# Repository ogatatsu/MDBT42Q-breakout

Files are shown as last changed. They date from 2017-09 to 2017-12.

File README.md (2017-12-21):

# MDBT42Q-breakout

Raytac社製nRF52832モジュールMDBT42Qのブレークアウト基板です。

RedBearLabのBLE Nanoの書き込み機(Daplink)を直接挿して書き込みできるようにしました。

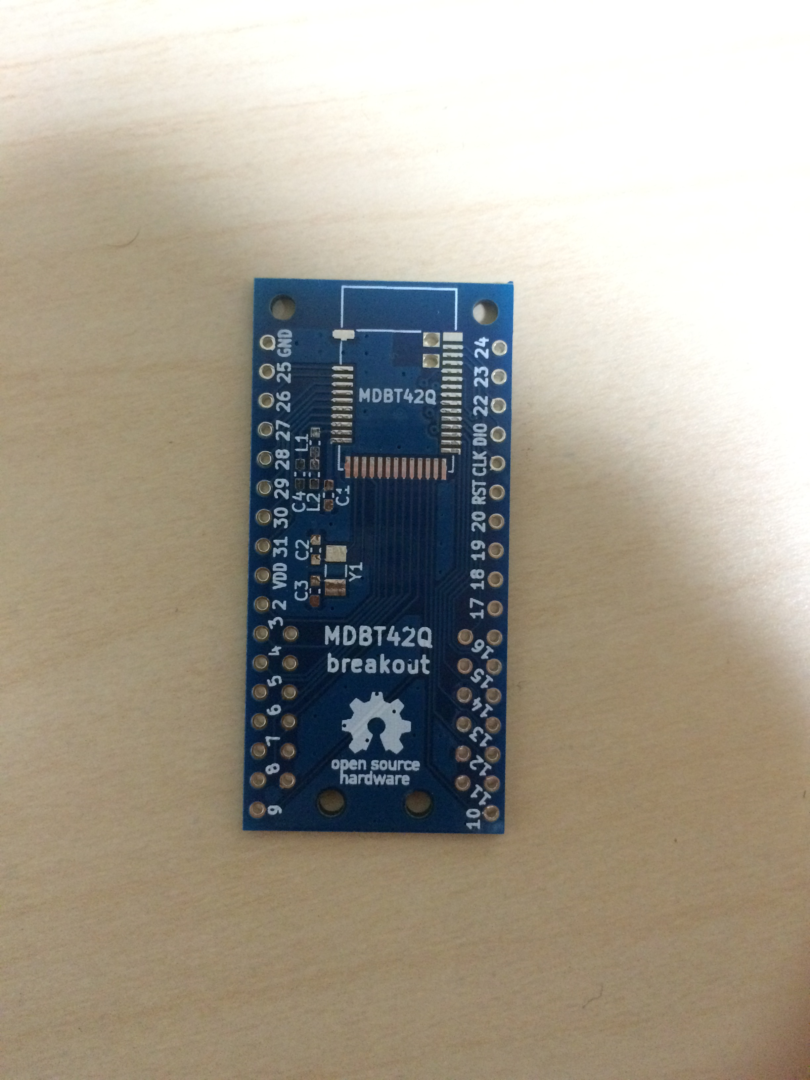
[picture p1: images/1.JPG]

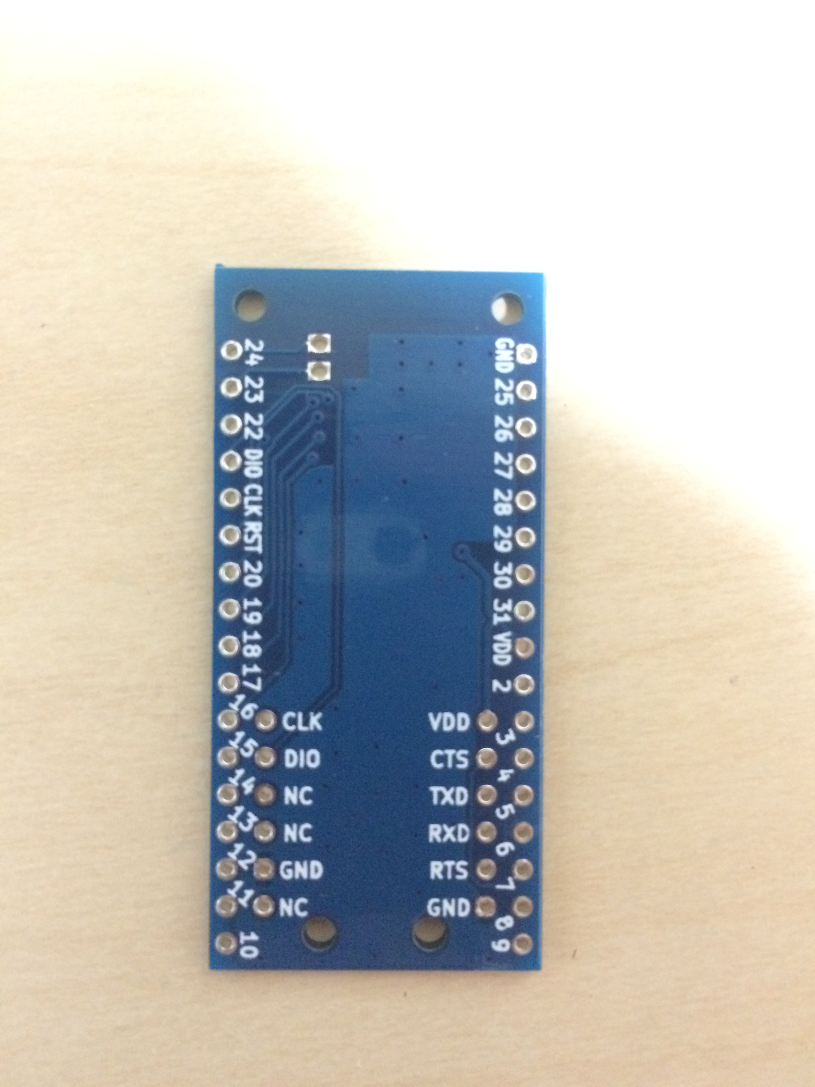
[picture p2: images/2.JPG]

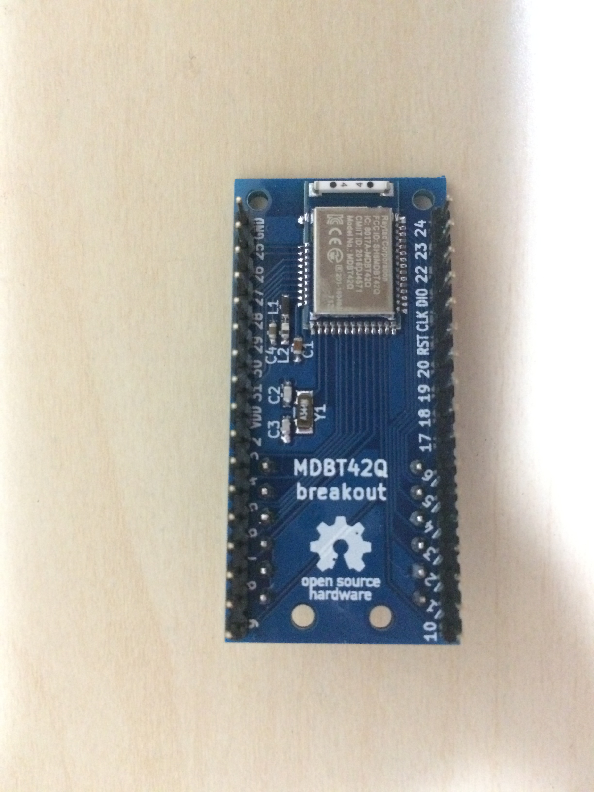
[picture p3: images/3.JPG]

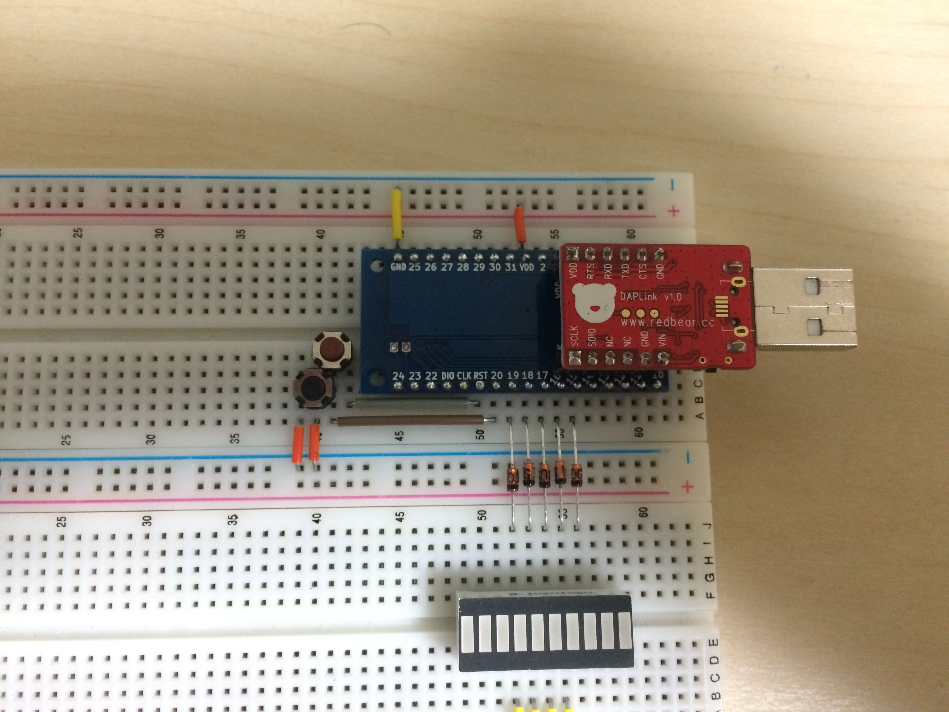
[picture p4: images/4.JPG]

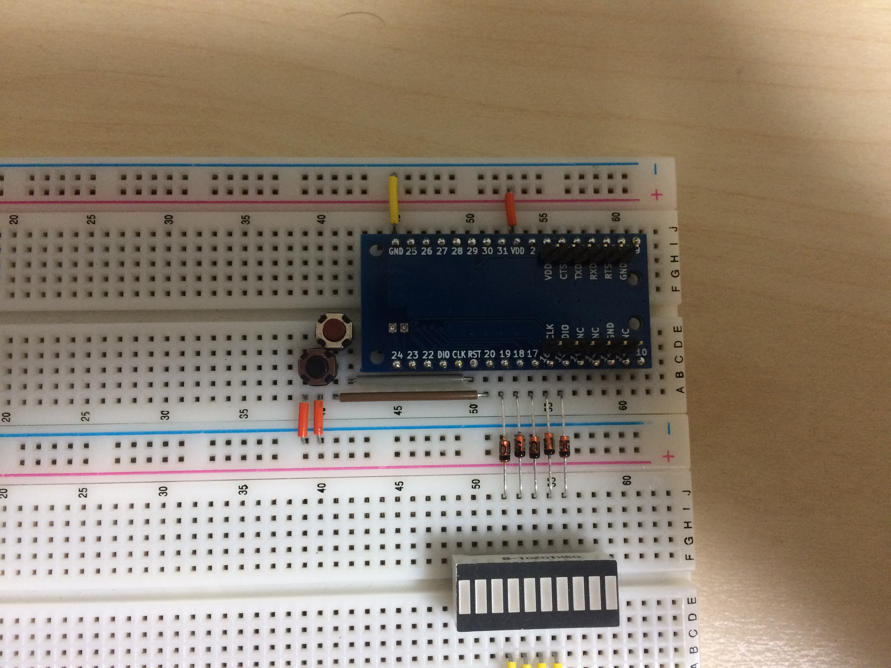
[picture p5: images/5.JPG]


コンデンサ、インダクタはすべて1608サイズ、水晶振動子はFC-135です。
コンデンサC2,C3の容量は水晶振動子の負荷容量に合わせて選定してください。
コンデンサはその辺の店に売ってると思いますがインダクタはなかなか厳しいと思いますので私が使用したものの入手先を貼っておきます。

- 15nH
  - https://www.digikey.jp/product-detail/ja/taiyo-yuden/HK160815NJ-T/587-1547-1-ND/1008162
  - https://www.marutsu.co.jp/GoodsDetail.jsp?q=HK160815NJ-T&salesGoodsCode=15560264
- 10µH
  - https://www.digikey.jp/product-detail/ja/taiyo-yuden/LBMF1608T100K/587-1714-1-ND/1008036
  - https://www.marutsu.co.jp/GoodsDetail.jsp?q=LBMF1608T100K&salesGoodsCode=15560538

## License

https://creativecommons.org/licenses/by/4.0/

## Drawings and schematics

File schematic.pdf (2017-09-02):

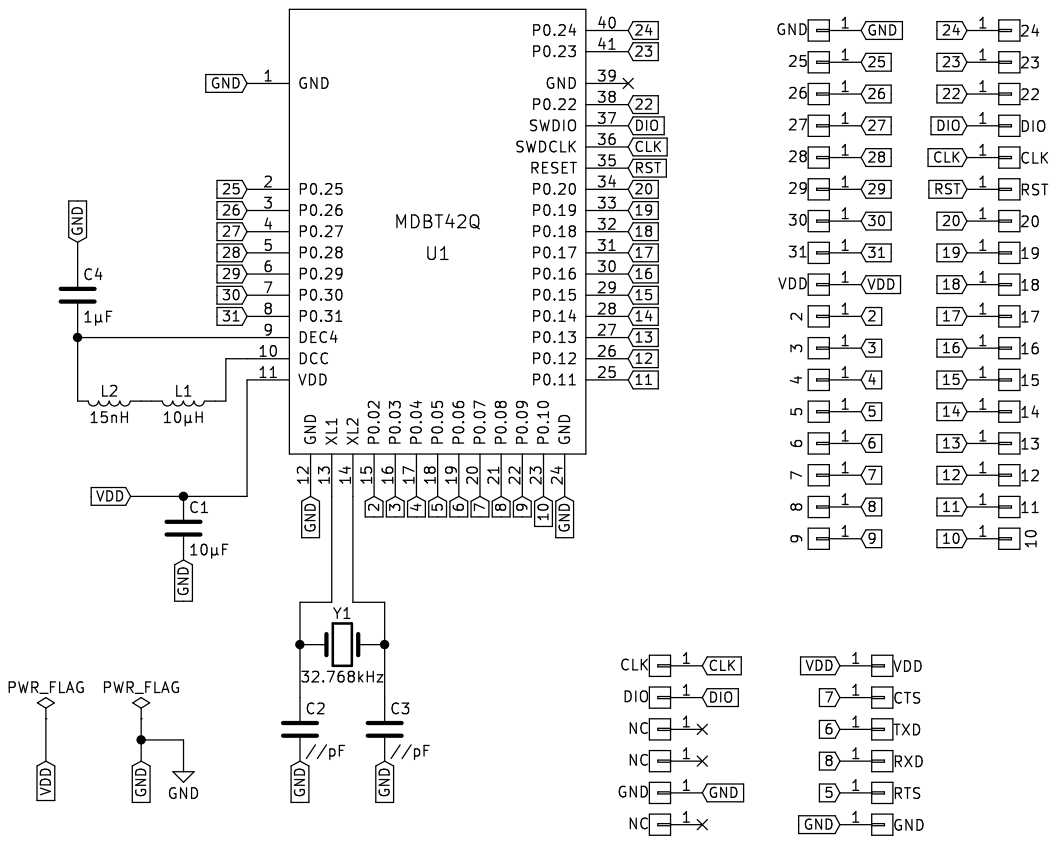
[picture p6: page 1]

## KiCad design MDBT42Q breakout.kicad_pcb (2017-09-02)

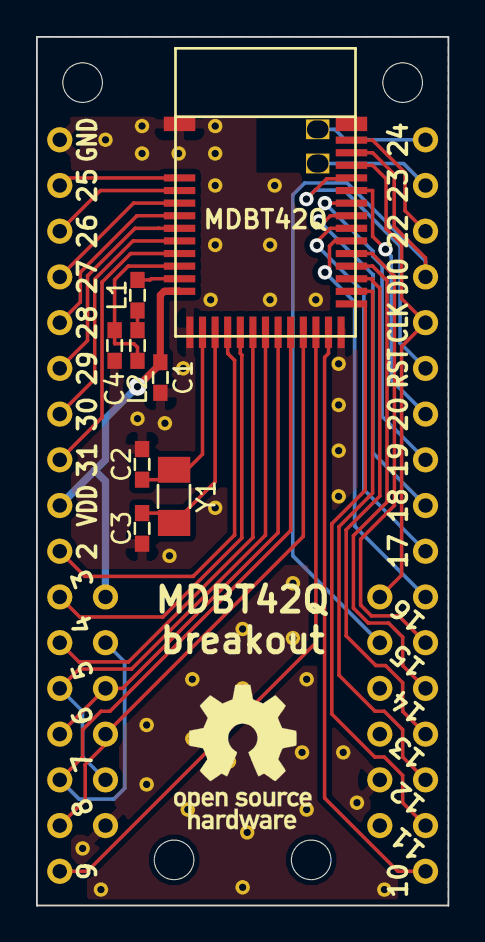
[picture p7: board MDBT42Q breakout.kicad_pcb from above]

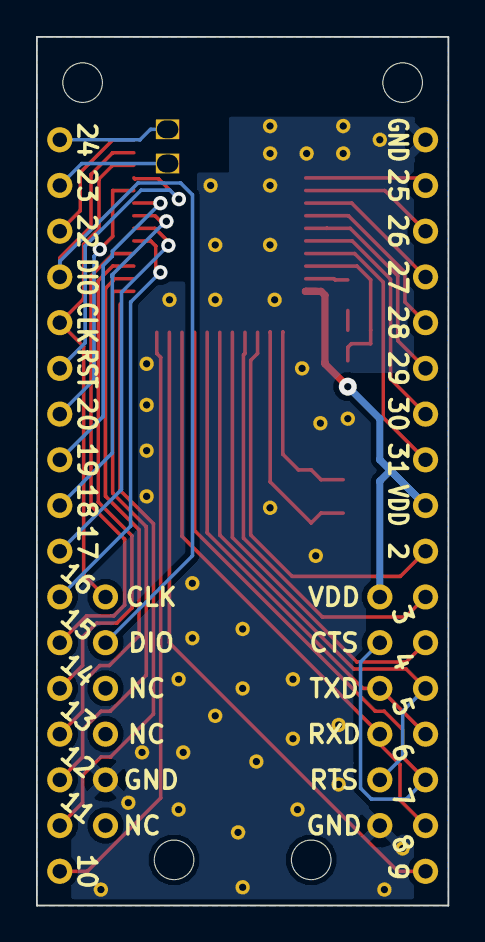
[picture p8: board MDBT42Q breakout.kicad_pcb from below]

Board: 2 copper layers, 22.9 x 48.3 mm, 54 parts (12 on the bottom side), 39 nets.

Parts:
C1: 10μF; 1608
C2, C3: //pF; 1608
C4: 1μF; 1608
J1: 25; Wirepad
J2: 26; Wirepad
J3: 27; Wirepad
J4: 28; Wirepad
J5: 29; Wirepad
J6: 30; Wirepad
J7: 31; Wirepad
J8, J41: VDD; Wirepad
J9: 2; Wirepad
J10: 3; Wirepad
J11: 4; Wirepad
J12: 5; Wirepad
J13: 6; Wirepad
J14: 7; Wirepad
J15: 8; Wirepad
J16: 9; Wirepad
J17: 10; Wirepad
J18: 24; Wirepad
J19: 23; Wirepad
J20: 22; Wirepad
J21, J36: DIO; Wirepad
J22, J35: CLK; Wirepad
J23: RST; Wirepad
J24: 20; Wirepad
J25: 19; Wirepad
J26: 18; Wirepad
J27: 17; Wirepad
J28: 16; Wirepad
J29: 15; Wirepad
J30: 14; Wirepad
J31: 13; Wirepad
J32: 12; Wirepad
J33: 11; Wirepad
J34, J39, J46: GND; Wirepad
J37, J38, J40: NC; Wirepad
J42: CTS; Wirepad
J43: TXD; Wirepad
J44: RXD; Wirepad
J45: RTS; Wirepad
L1: 10μH; 1608
L2: 15nH; 1608
U1: MDBT42Q
Y1: 32.768kHz; FC-135

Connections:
2: J9.1, U1.15
3: J10.1, U1.16
4: J11.1, U1.17
5: J12.1, J45.1, U1.18
6: J13.1, J43.1, U1.19
7: J14.1, J42.1, U1.20
8: J15.1, J44.1, U1.21
9: J16.1, U1.22
10: J17.1, U1.23
11: J33.1, U1.25
12: J32.1, U1.26
13: J31.1, U1.27
14: J30.1, U1.28
15: J29.1, U1.29
16: J28.1, U1.30
17: J27.1, U1.31
18: J26.1, U1.32
19: J25.1, U1.33
20: J24.1, U1.34
22: J20.1, U1.38
23: J19.1, U1.41
24: J18.1, U1.40
25: J1.1, U1.2
26: J2.1, U1.3
27: J3.1, U1.4
28: J4.1, U1.5
29: J5.1, U1.6
30: J6.1, U1.7
31: J7.1, U1.8
CLK: J22.1, J35.1, U1.36
DIO: J21.1, J36.1, U1.37
GND: C1.2, C2.2, C3.2, C4.1, J34.1, J39.1, J46.1, U1.1, U1.12, U1.24
unnamed: C2.1, U1.13, Y1.1
unnamed: C3.1, U1.14, Y1.2
unnamed: C4.2, L2.2, U1.9
unnamed: L1.1, U1.10
unnamed: L1.2, L2.1
RST: J23.1, U1.35
VDD: C1.1, J8.1, J41.1, U1.11

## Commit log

2017-09-02 add schematic
2017-09-02 change c2 c3 capacity
    [MDBT42Q breakout.kicad_pcb, MDBT42Q breakout.sch]
2017-09-02 change schematic
2017-11-05 libファイルが入っていなかったので追加
